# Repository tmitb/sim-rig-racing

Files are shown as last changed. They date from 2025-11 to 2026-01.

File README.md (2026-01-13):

# Racing Sim
This is a repository for tracking progresses and history about all things `Racing Sim` that are related to my own rigs. This `README` Section will log all the progress below, showing the most recent changes first. Each project folder may be referred in this document for more details, and items.

## Current Setup
### Controllers
- MOZA racing R5
- MOZA racing ES wheel
- MOZA racing Sequential Shifter
- MOZA racing CRP2 Throttle
- MOZA racing mBoost Active Pedal(Brake)
- Cheap Chineses Hall sensor Handbrake(not mounted yet)

### Display
- TCL 55" QM6K x3 @ 1440p, 120hz
- LG 32GK650F @ 1440p, 60hz

### Computer Hardware
- AMD Ryzen 7 5800X3D
- Asus TUF RTX 5090
- 128GB memory DDR4 3200Mhz
- Logitech K400 Wireless keyboard+touchpad
- 4 Channels of 25W bass shakers driven by two small Class D amps (only three channels are used for now)

### Frame
- [Custom built wooden frame](https://github.com/tmitb/sim-rig-racing/tree/main/wooden-frame#readme)

### Noteworthy accessories
- Ventilated seat pad [Aliexpress link](https://www.aliexpress.com/item/1005007196227825.html?spm=a2g0o.order_list.order_list_main.5.4b971802pqZyDx)
  - I absolutely love it.
  - If it gets too hot and you sweat sitting in too long for a session, this is a great accessory to get under $50.
  - You need to get 12v DC adapter from somewhere. I had one laying around in my DC adaptor pile, but you may need to get one. It requires 2A at 12v.
  - It is a bit noisy, so if you want to speak with an open mic, probably not a good option.

# License
Unless specified otherwise, All 3D models are CC BY-SA 4.0, and software portion is MIT License.

# History Log
## Setup updated (2026-1-13)
I have moved on to triple display setup. With it, I had finished couple phases of my custom built wooden frame project. For more information, follow the link above in the frame section.

## Foot rest/Riser added (2025-11-30)

## Repo is born (2025-11-26)
The repo is born this day with something inside for the first time. I am in process of collecting some data for the current sim setup, which is quite meassy to say the least.

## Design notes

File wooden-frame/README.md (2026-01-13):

# Wooden frame
I have implemented two phases of the rig build. There is bits of build logs for each phase below.

## Requirements
- Triple screen setup
- Isolated platform between screens and rig
- Center console
- Dash

## Build log
### Phase 1
I have built a stand to test out 43" Single TV setup.

#### BOM
- 2x6 104" 5/8 dimensional lumber x2
- 2" 1/2 deck screw x25
- TV wall mount

#### Description
I had a bunch of 2x6 104" 5/8 dimensional lumber that I bought in the cull lumber lot at a local hardware store. It costed me about 50 Loonies(Canadian dollar) for 30 pcs. Being cull lumbers, some of them are only partially usable or bent a bit, I picked some of the straighter ones to build the stand.

The stand required 2pcs of 2x6 104" 5/8. Each pcs were cut twice to end up with 2pcs 33" and 1pc 38" 1/2.
A 33" piece and 38" 1/2 piece form a T-shaped to serve as a leg, where longer piece is standing vertically. After the two were created, I put a 33" on top of two foot, then place the last 33" piece to form a face plate which is screwed to the top and two legs act as a face plate and a brace at the same time. Then a TV wall mount was added to the face place. I bought the mount in a local surplus shop for 25 Loonies when it was on sale.

After taxes and some screws, which I bought in bulk about 10 years ago, it will come out about 35 Loonies (around USD 25 at the time of the writing).

### Phase 2
After about a week trial with the single TV setup, I have decided to move on with the triple TV setup.

#### BOM
- 2x6 104" 5/8 dimensional lumber x7
- scrap 2x4 pieces varies in length x4
- 2" 1/2 deck screw x100
- TV wall mount x2
- Sub-floor tile (24"x24") x3
- Monitor Arm

#### Description
The focus was on the platform for the pedal, seat, and steering wheel mount. I have been using a cheap Amazon mount for a bit. I liked the chair so that was keept but the shaky pedal mount and wheel mount must go.

For the basic platform, I have cut 2x6 104" 5/8 in to two pieces, one that is 21 inches, and the other 72 inches to form a 24"x72" base platform. This required two pieces of the lumber and left with some scraps. Once the base was created, I went to a local hardware store to source some plywood panels, then I stumbled upon a 24"x24" sub-flooring tile. The tile has tounge and groove. It had a plastic bottom. It had correct dimensions. AND it was cheaper than buying plywood panels!. So I just changed the course and brought back 3 tiles. It has plastic bottom with OBS top, which is not ideal because you will get splinters overtime. So I filpped it and used the plastic parts as the top surface. It has dimples on it to create moisture pass when used as sub-flooring, but that was not needed for me. It is just better grippy surface for shoes, though I only where socks when driving. It will provide me a good accupressure treatment everyday.

Then I cut the last dimensional lumber to 3 pieces, 2x 26" 1/2 and 1x 27. I attached two shorter pieces to the platform to create a leg then put the top piece across them to make the stand for the wheel to mount eventually.

Then I started mount the pedal and seat. Pedal mounting was straight forward, just screwed them in to the floor. The seat needs to be boxed in by screwing in some scrap blocks around it. One of the scrap piece is placed to also prvent the seat from lifting by grabbing a small tounge in the chair. I mounted my open case to the space in front of the pedals to finish the build. Once built, I slide the entire platfrom undernethe the center TV stand.

I have 3D printeted the wheel to the stand mount. I was designing something that I can do a bit of telescoping, but gave up on it after couple hours because I just wanted to play with all the new fancy toys, and there isn't a way to adjust the seat anyways so no point on spending extra time provoding adjustability to the wheel itself. However, I will for sure to get to the sliding seat and tilt/telescoping one day.

I played a bit after the platform was built and before two extra TVs were put in places. Everything was rock sturdy and I am really happy with the result.

With one already built, I needed two more identical stands. That was done in no time. The challenge was to align them correctly. First, I adjusted one side based on my peripheral vision and amount of head movement I have when I drive a real car. Then bring a letter size paper to the point where two screen meets, and then fold one side to find the angle. Use this paper as a template, I adjusted another monitor to match exact angle. After that, I downloaded a protractor app and used that to find the exact number and put that to the game I had.

It took two entire days to complete the build. The entire experiance is fantastic. Having a pole to win session on the first race after completing the rig build was a cherry on top.

Having RTX5090 gave me a good(or bad depending on how you see it) idea of having an extra monitor on top of the center because RTX5090 can drive up to 5 mointors and I had one monitor laying around. So I got a monitor arm and mounted to the center stand. This will have OBS on for my streaming, though the streaming is more of an archieving rather than showing it to others.

This concludes the Phase 2, which is the major part of the build. I have some other ideas, mainly accessory mounts and center console, but nothing solid yet.

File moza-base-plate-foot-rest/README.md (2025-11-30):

# MOZA racing base plate foot rest
I found myself having a difficulty using MOZA racing CRP2+mBoost pedal when I first got it. I have pretty small foot and the height of the pedeal plate and the action was not comfortable at all for my small foot. After some fiddling around I created models that can help me adjust the foot rest height.

The models have 1cm in height so you can easily increse the height by printing more plates. Because the bolt hole of the MOZA racing base plate is M4, you need at least M4x10mm bolt to secure the riser base plate. Each layer you add requires 4pcs of M3 heat insert and 4 pcs of M3x10mm. I initially wanted to match all screws to M4s but I did not have M4 heat inserts and extra screws so it must do with M3s.

If you decided to use the foot rest, a > shaped metal bar, you need additional 2 pcs of M3 heat inserts and 2 pcs of M3 screws. Note that this heat insert recieves enourmous pressure from the foot if you lean your foot on it. I would like to suggest to use longest possible heat inserts for this and matching screw to have more surface for the mechanical parts to bite to each other.

# Printing
I used BambuLabs P1S's default settings for Generic PLA, and Soleyin PLA filament. When the model is put on to the slicer, you will find that the model does not really fit.
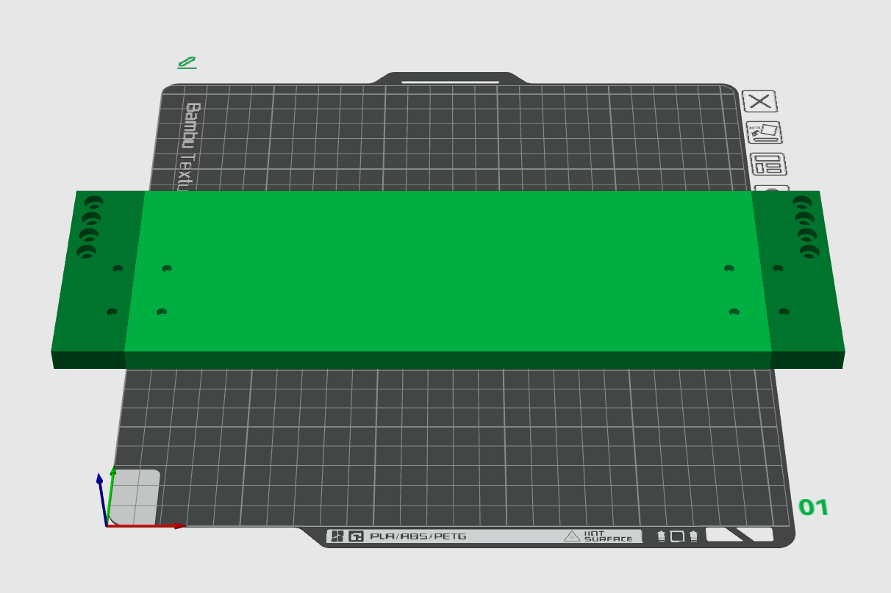
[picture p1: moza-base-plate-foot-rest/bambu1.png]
Too large?

However, you can rotate the model then it will be perfectly fine to be printed in P1S. You can add 90 to X-axis and 135 to Z-axis.
 
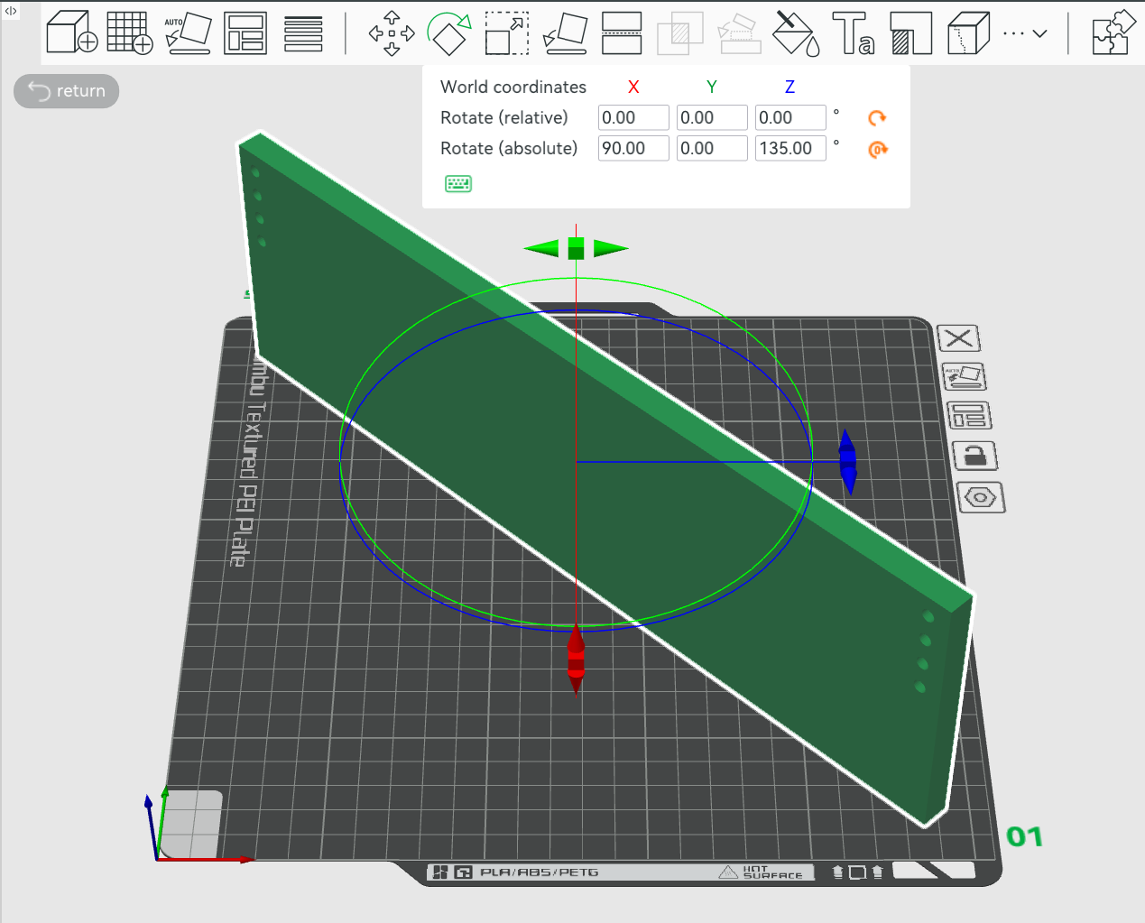
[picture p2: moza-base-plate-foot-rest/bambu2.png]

you can do up to 4 plates at the same time.

# Assembly
The riser top can be flip to have different hole pattern for assembly. You can stack a plate on top of another and hold them down. You can use the holes criss-corss pattern to keep stack up. The bottom plate should have heat inserts for matching holes for the plate going on top of them.

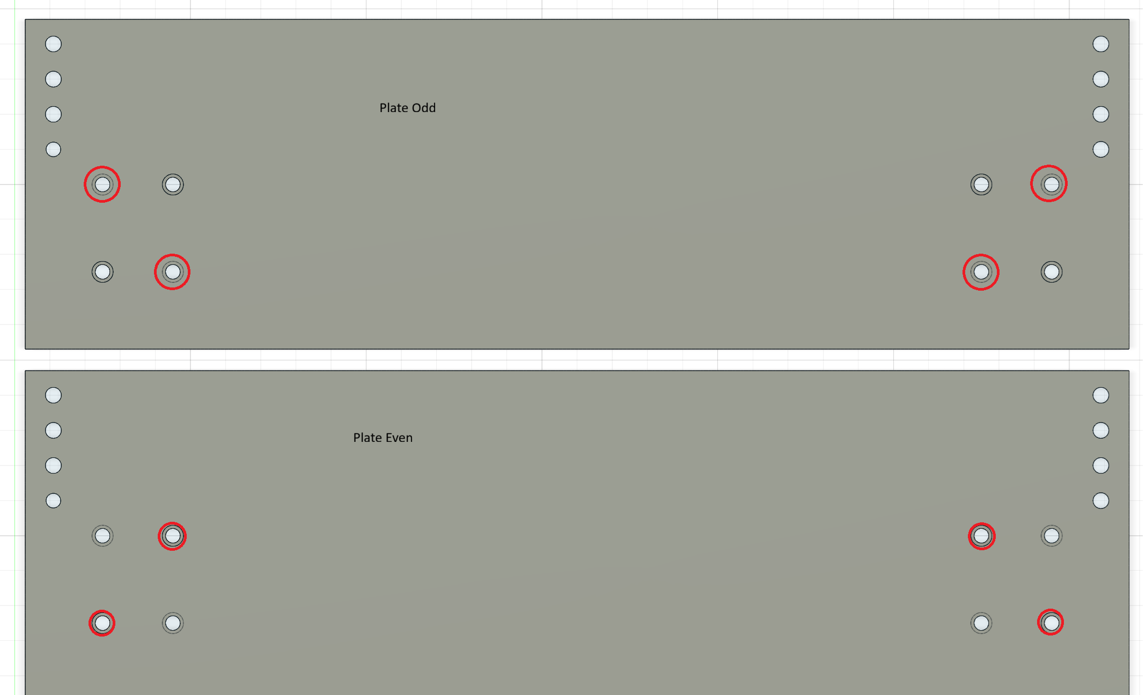
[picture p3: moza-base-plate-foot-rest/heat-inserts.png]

Heat inserts for the holes with red circles. Of course you need to flip the plates for odd and even.

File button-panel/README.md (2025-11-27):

# Button panel
I would like to create a panel of buttons to control more things withoutt sacrificing buttons on the wheel, which has limited numbers.

The item will be built as a gaming controller using MCU, aruino nano or esp32. But I have not decide other things yet

## Requirements
TBA

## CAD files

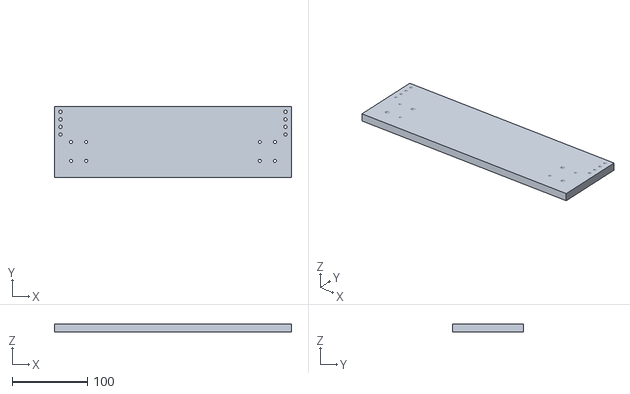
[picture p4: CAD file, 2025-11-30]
moza-base-plate-foot-rest/riser top.stl
314.0 x 94.0 x 10.0

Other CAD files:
moza-base-plate-foot-rest/riser base plate.stl
moza-base-plate-foot-rest/riser base plate.f3d
moza-base-plate-foot-rest/riser top.f3d

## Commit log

2025-11-27 added button panel project folder
2025-11-30 added foot rest riser
    [riser base plate.f3d, riser base plate.stl, riser top.f3d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]
